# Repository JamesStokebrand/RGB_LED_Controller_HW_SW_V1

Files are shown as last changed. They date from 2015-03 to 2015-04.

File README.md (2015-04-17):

RGB LED Controller and Node Project Version 1:

This is the Software/Hardware for the Controller.

parts_list:
- Parts list pulled from EagleCAD project.
- Parts list spreadsheet listing quantity, parts numbers and supplier URLs.

src_code:
- CPP source code:
  * Makefile for AVR ATmega328p
  * XBee UART Driver and Communication wrapper
  * Support for AVR sleep and power reduction
  * Software based PWM (Timer based)
  * Timer class
  * RGB Controller State Machine
  * Button and rotary encoder input support

pcb_details:
- PCB Top/Bottom PNGs
- Eagle CAD schematic

PCBs are available for order on OSH Park:
https://oshpark.com/shared_projects/0rVsBJ7Y

project_case:
- project case files in STL format with associated photos

Further information on this project can be found here:
https://jamesstokebrand.wordpress.com/category/rgb-led-controller-and-node-v1/

14 Mar 2015 - Initial Commit 

23 Mar 2015 - Added Schematics and Project Cases

17 Apr 2015 - Updated source code to update mcu sleeping.

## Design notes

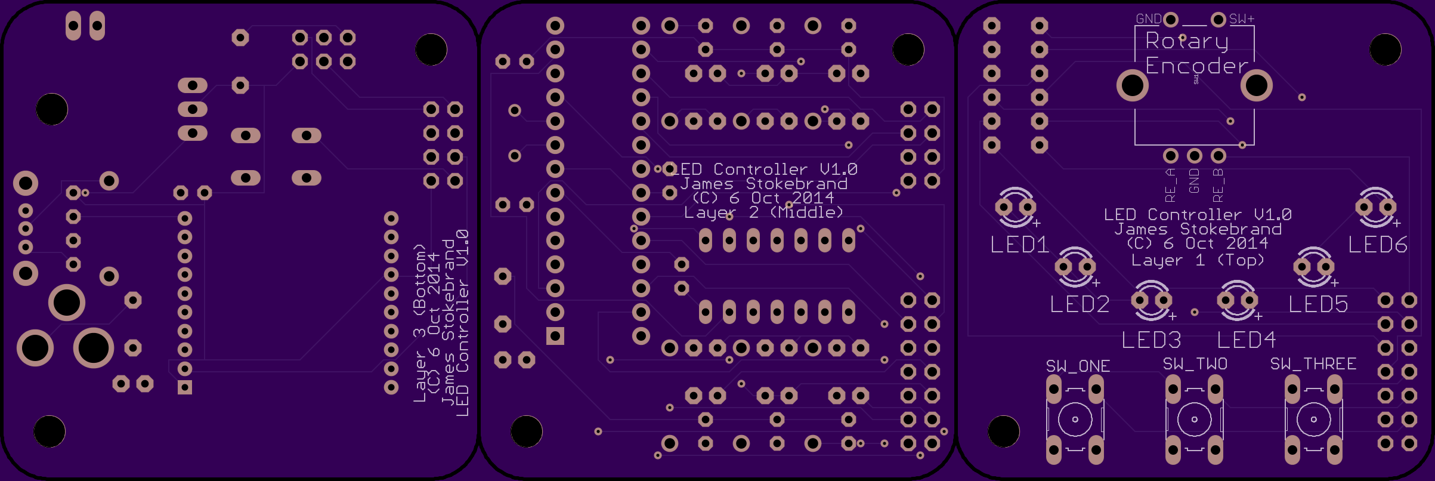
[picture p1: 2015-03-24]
pcb_details/Controller_PCB_Bottom_V1.png

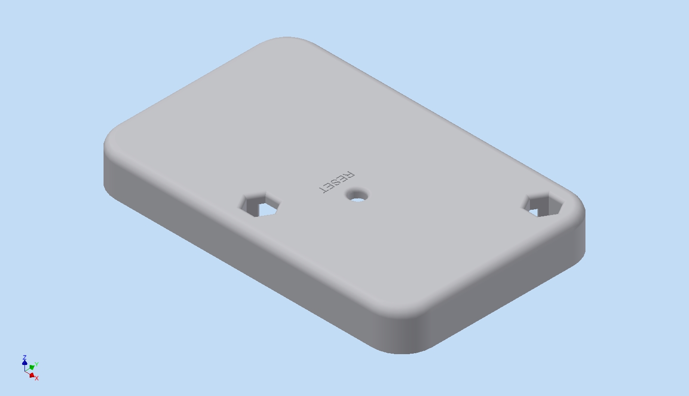
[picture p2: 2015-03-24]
project_case/Controller_Shell_Bottom_V1.jpg

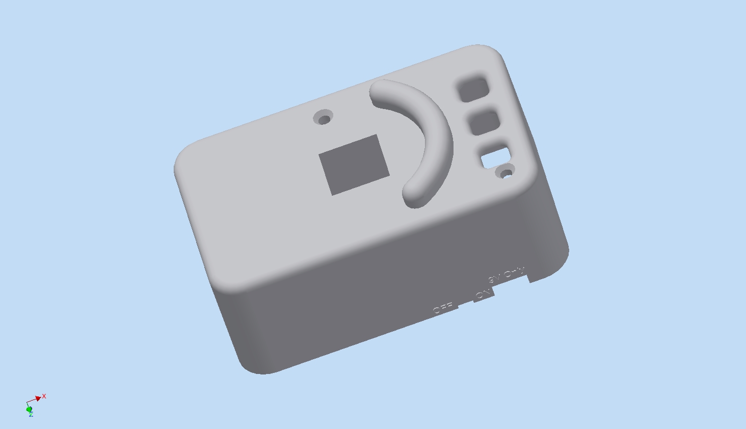
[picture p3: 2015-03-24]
project_case/Controller_Shell_Top_V1.jpg

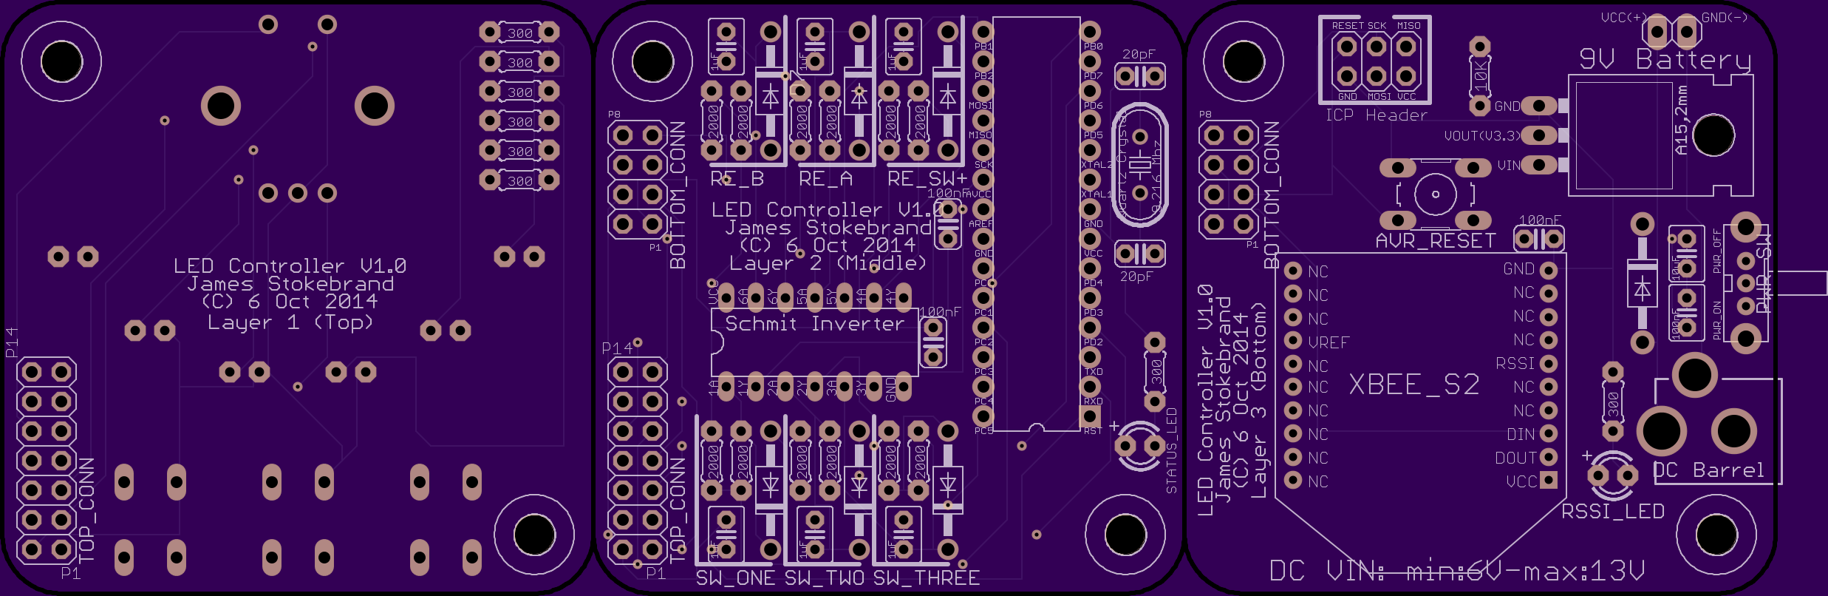
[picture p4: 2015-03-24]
pcb_details/Controller_PCB_Top_V1.png

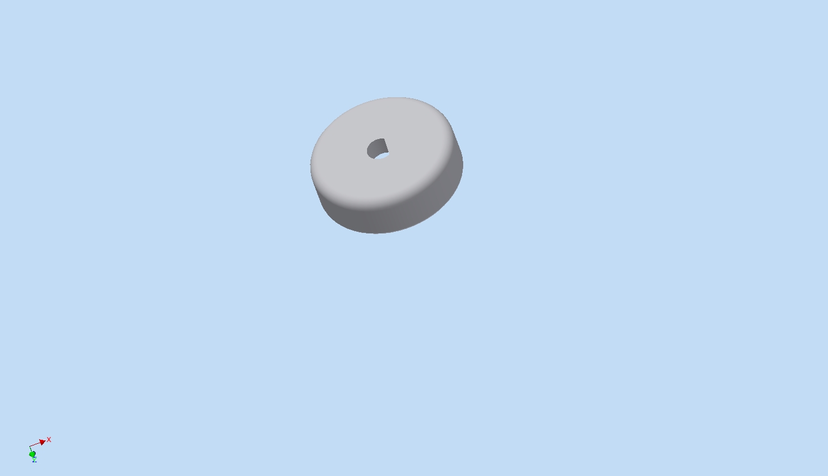
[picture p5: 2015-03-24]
project_case/Controller_Shell_Knob_v1.jpg

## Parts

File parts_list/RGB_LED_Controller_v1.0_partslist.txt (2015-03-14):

Partlist

Exported from ATmega328p_XBee_Devboard_v1.5.brd at 10/7/14 6:18 PM

EAGLE Version 6.6.0 Copyright (c) 1988-2014 CadSoft

Assembly variant: 

Part       Value                   Package          Library                       Position (inch)       Orientation

C1         100nF                   C025-030X050     adafruit                      (5.75 1)              R90
C2         10uF                    C025-030X050     adafruit                      (5.75 1.2)            R270
C3         100nF                   C025-024X044     adafruit                      (3.25 1.3)            R270
C4         20pF                    C025-024X044     adafruit                      (3.9 1.2)             R180
C5         1uF                     C025-030X050     adafruit                      (3.1 0.25)            R90
C6         1uF                     C025-030X050     adafruit                      (3.1 1.9)             R270
C7         1uF                     C025-030X050     adafruit                      (2.5 0.25)            R90
C8         1uF                     C025-030X050     adafruit                      (2.8 0.25)            R90
C9         20pf                    C025-024X044     adafruit                      (3.9 1.8)             R180
C10        1uF                     C025-030X050     adafruit                      (2.8 1.9)             R270
C11        1uF                     C025-030X050     adafruit                      (2.5 1.9)             R270
C12        100nF                   C025-024X044     adafruit                      (3.2 0.9)             R270
C13        100nF                   C025-024X044     adafruit                      (5.25 1.25)           R0
CN1        DC Barrel Jack          DCJACK_2MM_PTH   adafruit                      (6.2 0.6)             R90
D1         1N4004                  DO41-10          adafruit                      (5.6 1.1)             R270
D2         1N4004                  DO41-10          diode                         (2.65 0.4)            R90
D3         1N4004                  DO41-10          diode                         (3.25 0.4)            R90
D4         1N4004                  DO41-10          diode                         (3.25 1.75)           R270
D5         1N4004                  DO41-10          diode                         (2.95 0.4)            R90
D6         1N4004                  DO41-10          diode                         (2.95 1.75)           R270
D7         1N4004                  DO41-10          diode                         (2.65 1.75)           R270
IC1        LD117AV33               TO220L1          v-reg                         (5.4 1.6)             R270
ICP_HEADER                         2X03             pinhead                       (4.7 1.85)            R180
JP1                                2X04             pinhead                       (2.2 1.45)            R90
JP2                                2X04             pinhead                       (4.2 1.45)            R90
JP3                                2X07             pinhead                       (0.2 0.5)             R90
JP4                                2X07             pinhead                       (2.2 0.5)             R90
JP5                                1X02             pinhead                       (5.7 1.95)            R0
LED1       3mm RED                 LED3MM           adafruit                      (1.8 1.19)            MR180
LED2       3mm RED                 LED3MM           adafruit                      (1.55 0.94)           MR180
LED3       3mm RED                 LED3MM           adafruit                      (1.23 0.8)            MR180
LED4       3mm RED                 LED3MM           adafruit                      (0.87 0.8)            MR180
LED5       3mm RED                 LED3MM           adafruit                      (0.55 0.94)           MR180
LED6       3mm RED                 LED3MM           adafruit                      (0.29 1.19)           MR180
LED7       3mm RED                 LED3MM           adafruit                      (5.5 0.45)            R0
LED8       3mm RED                 LED3MM           adafruit                      (3.9 0.55)            R0
R1         300 Ohm                 0204/5           adafruit                      (1.8 1.95)            R0
R2         300 Ohm                 0204/5           adafruit                      (1.8 1.85)            R0
R3         300 Ohm                 0204/5           adafruit                      (1.8 1.75)            R0
R4         300 Ohm                 0204/5           adafruit                      (1.8 1.65)            R0
R5         2K                      0204/5           adafruit                      (3.05 0.5)            R270
R6         2K                      0204/5           adafruit                      (3.15 0.5)            R270
R7         2K                      0204/5           adafruit                      (3.05 1.65)           R90
R8         2K                      0204/5           adafruit                      (3.15 1.65)           R90
R9         10K Ohm                 0204/5           adafruit                      (5.05 1.8)            R90
R10        2K                      0204/5           adafruit                      (2.45 0.5)            R270
R11        2K                      0204/5           adafruit                      (2.55 0.5)            R270
R12        2K                      0204/5           adafruit                      (2.75 0.5)            R90
R13        2K                      0204/5           adafruit                      (2.85 0.5)            R270
R14        300 Ohm                 0204/5           adafruit                      (3.95 0.8)            R270
R15        2K                      0204/5           adafruit                      (2.75 1.65)           R90
R16        2K                      0204/5           adafruit                      (2.85 1.65)           R90
R17        2K                      0204/5           adafruit                      (2.55 1.65)           R90
R18        2K                      0204/5           adafruit                      (2.45 1.65)           R90
R19        300 Ohm                 0204/5           adafruit                      (1.8 1.55)            R180
R20        300 Ohm                 0204/5           adafruit                      (1.8 1.45)            R180
R21        300 Ohm                 0204/5           adafruit                      (5.5 0.7)             R270
S1         Swittch                 B3F-10XX         switch-omron                  (1.05 0.3)            MR270
S2         RESET                   B3F-10XX         switch-omron                  (4.9 1.4)             R0
S3         Swittch                 B3F-10XX         switch-omron                  (0.55 0.3)            MR270
S5         Swittch                 B3F-10XX         switch-omron                  (1.55 0.3)            MR270
S6         EG1213                  EG1213           adafruit                      (5.95 1.1)            R90
SW1        ROTARTY_ENCODER         ROTARY_ENC_PLAIN SparkFun-Electromechanical    (1.05 1.7)            MR270
U1         ATMEGA328P-PU-1030050P1 DIP28            OPL_Eagle_Library_Seeed_Sudio (3.55 1.3)            R180
V1         7414N                   DIL14            74ttl-din                     (2.8 0.9)             R0
XBEE       XBEE                    XBEE             adafruit                      (4.85 0.65)           R180
Y1          9.216 Mhz              HC49U-V          SparkFun-FreqCtrl             (3.9 1.5)             R90

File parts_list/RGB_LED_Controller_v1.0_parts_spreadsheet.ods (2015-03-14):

10/03/14 | Atmega328P Xbee Development Board v1.5
Count | Part Name/Description | Pins/Pkg | Pin Spacing | Manuf Part # | Supplier | Supplier Part # | Price Ea (~) | Total | URL
1 | 74HC14 IC INV HEX SCHMITT TRIG 14-DIP | DIP14 | 0.1”(2.54mm) | TC74HC14AP(F) | Digikey | TC74HC14APF-ND | 0.51 | 0.51 | http://www.digikey.com/product-detail/en/TC74HC14AP%28F%29/TC74HC14APF-ND/870479
1 | CONN IC SOCKET VERT 14POS TIN | DIP14 | 0.1”(2.54mm) | ED14DT | Digikey | ED3045-5-ND | 0.17 | 0.17 | http://www.digikey.com/product-detail/en/ED14DT/ED3045-5-ND/4147595
1 | 3.3v Voltage Regulator | 3 | 0.1”(2.54mm) | LD1117V33 | Digikey | 497-1491-5-ND | 0.64 | 0.64 | http://www.digikey.com/product-detail/en/LD1117V33/497-1491-5-ND/586012
4 | CAP CER 0.1UF 25V RADIAL (100nF) | 2 | 0.1”(2.54mm) | FK18X7R1E104K | Digikey | 445-8421-ND | 0.29 | 1.16 | http://www.digikey.com/product-detail/en/FK18X7R1E104K/445-8421-ND/2815351
2 | CAP CER 20PF 50V 5% RADIAL | 2 | 0.1”(2.54mm) | C317C200J5G5TA | Digikey | 399-8916-ND | 0.51 | 1.02 | http://www.digikey.com/product-detail/en/C317C200J5G5TA/399-8916-ND/3522973
1 | CAP CER 10UF 25V 10% RADIAL | 2 | 0.1”(2.54mm) | FK16X7R1E106K | Digikey | 445-8351-ND | 0.65 | 0.65 | http://www.digikey.com/product-detail/en/FK16X7R1E106K/445-8351-ND/2815281
6 | CAP CER 1UF 25V 10% RADIAL | 2 | 0.1”(2.54mm) | FK18X5R1E105K | Digikey | 445-8410-ND | 0.34 | 2.04 | http://www.digikey.com/product-detail/en/FK18X5R1E105K/445-8410-ND/2815340
1 | CRYSTAL 9.216MHZ 20PF THRU | 2 | 4.8mm | ECS-92.1-20-4X | Digikey | X1096-ND | 0.81 | 0.81 | http://www.digikey.com/product-detail/en/ECS-92.1-20-4X/X1096-ND/827587
7 | LED SS RED DIFFUSED PCB 3MM | 2 | 0.1”(2.54mm) | MV50640 | Digikey | 1080-1100-ND | 0.42 | 2.94 | http://www.digikey.com/product-detail/en/MV50640/1080-1100-ND/2675591
1 | LED SS YELLOW DIFFUSED PCB 3MM | 2 | 0.1”(2.54mm) | MV5374C | Digikey | 1080-1106-ND | 0.46 | 0.46 | http://www.digikey.com/product-detail/en/MV5374C/1080-1106-ND/2675597
8 | RES 300 OHM 1/4W 1% AXIAL | 2 | 0.1”(2.54mm) | RNMF14FTC300R | Digikey | S300CACT-ND | 0.14 | 1.12 | http://www.digikey.com/product-detail/en/RNMF14FTC300R/S300CACT-ND/2617485
4 | SWITCH TACTILE SPST-NO 0.05A 24V | 4 | 6.5mmX4.5mm | B3F-1020 | Digikey | SW402-ND | 0.41 | 1.64 | http://www.digikey.com/product-detail/en/B3F-1020/SW402-ND/44059
1 | SWITCH SLIDE SPDT 30V RT ANGLE | 4 | Various | EG1213 | Digikey | EG1906-ND | 0.58 | 0.58 | http://www.digikey.com/product-detail/en/EG1213/EG1906-ND/101735
1 | Rotary Encoder | 7 | N/A | COM-09117 | Sparkfun | COM-09117 | 2.95 | 2.95 | https://www.sparkfun.com/products/9117
1 | ATMEGA328P-PU (IC MCU 8BIT 32KB FLASH 28DIP) | DIP28 | 0.1”(2.54mm) | ATMEGA328P-PU | Digikey | ATMEGA328P-PU-ND | 3.74 | 3.74 | http://www.digikey.com/product-detail/en/ATMEGA328P-PU/ATMEGA328P-PU-ND/1914589
1 | CONN IC SOCKET VERT 28POS TIN | DIP28 | 0.1”(2.54mm) | ED281DT | Digikey | ED3050-5-ND | 0.31 | 0.31 | http://www.digikey.com/product-detail/en/ED281DT/ED3050-5-ND/4147600
1 | DC Barrel Power Jack/connector | 3 | 4.7mm | PJ-002A | Digikey | CP-002A-ND | 0.93 | 0.93 | http://www.digikey.com/product-detail/en/PJ-002A/CP-002A-ND/96962
7 | DIODE GEN PURPOSE 50V 1A DO41 | 2 | N/A | 1N4001-TP | Digikey | 1N4001-TPMSCT-ND | 0.11 | 0.77 | http://www.digikey.com/product-detail/en/1N4001-TP/1N4001-TPMSCT-ND/773688
12 | RES 2K OHM 1/4W 1% AXIAL | 2 | 0.1”(2.54mm) | RNMF14FTC2K00 | Digikey | S2KCACT-ND | 0.14 | 1.68 | http://www.digikey.com/product-detail/en/RNMF14FTC2K00/S2KCACT-ND/2617814
1 | RES 10K OHM 1/4W 1% AXIAL | 2 | 0.1”(2.54mm) | RNMF14FTC10K0 | Digikey | S10KCACT-ND | 0.14 | 0.14 | http://www.digikey.com/product-detail/en/RNMF14FTC10K0/S10KCACT-ND/2617809
1 | MODULE ZIGBEE W/WIRED ANT | 20 | 0.079”(2mm) | XB24-Z7WIT-004 | Digikey | 602-1098-ND | 17 | 17 | http://www.digikey.com/product-detail/en/XB24-Z7WIT-004/602-1098-ND/1942304
2 | CONN RECEPT 2MM SINGLE STR 10POS (1x10 2mm strip XBEE Socket) | 10 | 0.079”(2mm) | NPPN101BFCN-RC | Digikey | S5751-10-ND | 1.23 | 2.46 | http://www.digikey.com/product-detail/en/NPPN101BFCN-RC/S5751-10-ND/804812
1 | CONN HEADER 6POS 2.54 (2x3) | 2x3 | 0.1”(2.54mm) | 61200621621 | Digikey | 732-5394-ND | 0.82 | 0.82 | http://www.digikey.com/product-detail/en/61200621621/732-5394-ND/4846913
1 | CONN HEADER FMALE 8PS .1" DL TIN (2x4) | 2x4 | 0.1”(2.54mm) | PPTC042LFBN-RC | Digikey | S7072-ND | 0.83 | 0.83 | http://www.digikey.com/product-detail/en/PPTC042LFBN-RC/S7072-ND/810211
1 | CONN HEADER FMAL 14PS .1" DL TIN (2x7) | 2x14 | 0.1”(2.54mm) | PPTC072LFBN-RC | Digikey | S7075-ND | 1.16 | 1.16 | http://www.digikey.com/product-detail/en/PPTC072LFBN-RC/S7075-ND/810213
1 | Header, straight, 0.1”(2.54mm) pitch, male 5.84mm high (2x36 pin headers) | 2x36 | 0.1”(2.54mm) | 67996-472HLF | Digikey | 609-3494-ND | 1.45 | 1.45 | http://www.digikey.com/product-detail/en/67996-472HLF/609-3494-ND/1486045
1 | 9V SNAP I STYLE 3" WIRE LEADS | 2 | 0.1”(2.54mm) | BS3I | Digikey | BS3I-ND | 0.59 | 0.59 | http://www.digikey.com/product-detail/en/BS3I/BS3I-ND/2439485
 | On Hand |  |  |  |  |  |  | 48.57
 | Ordered from Digikey

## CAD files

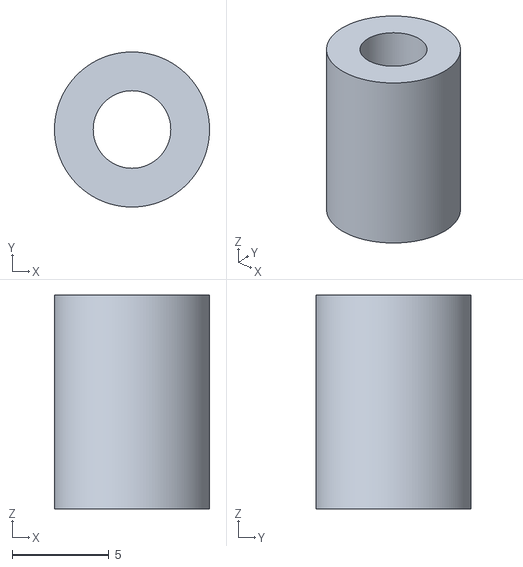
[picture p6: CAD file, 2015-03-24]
project_case/PCB_Spacer.stl
8.00 x 8.00 x 11.0

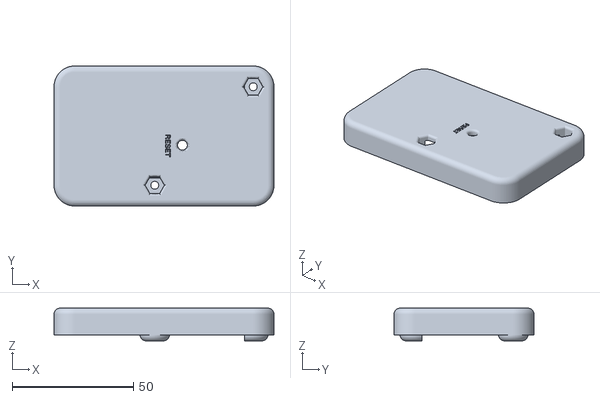
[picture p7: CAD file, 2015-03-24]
project_case/Controller_Shell_Top_V1.stl
90.8 x 57.8 x 13.5

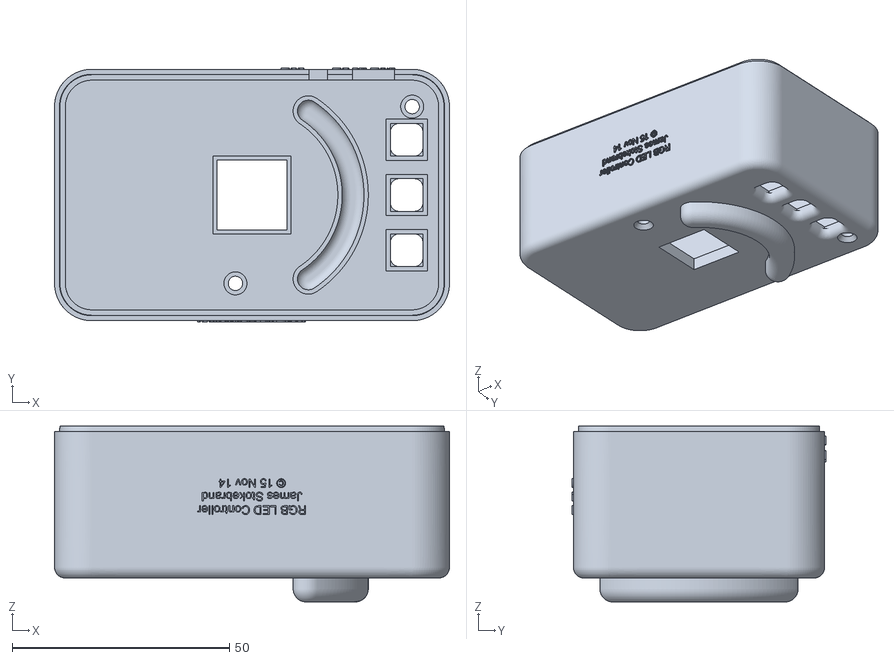
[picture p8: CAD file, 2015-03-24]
project_case/Controller_Shell_Bottom_V1.stl
90.8 x 58.5 x 40.5

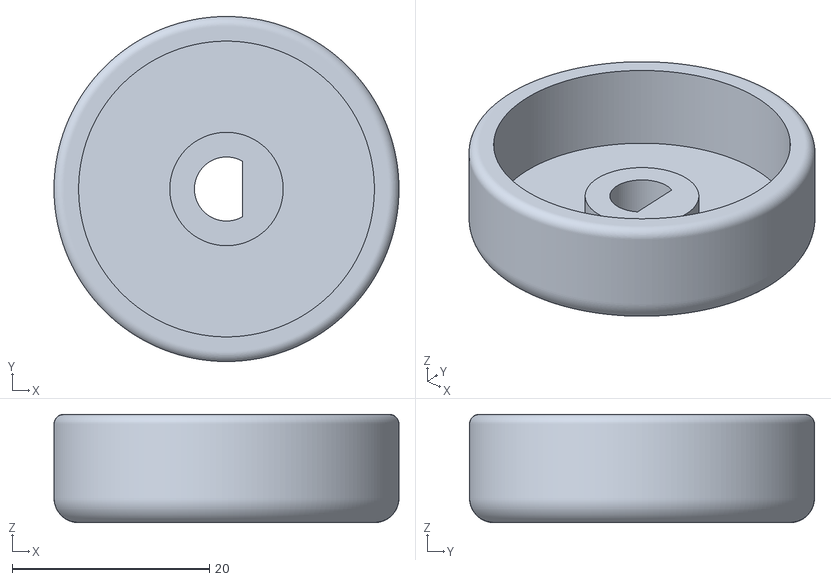
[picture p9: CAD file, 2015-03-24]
project_case/Controller_Shell_Knob_v1.stl
35.0 x 35.0 x 11.0

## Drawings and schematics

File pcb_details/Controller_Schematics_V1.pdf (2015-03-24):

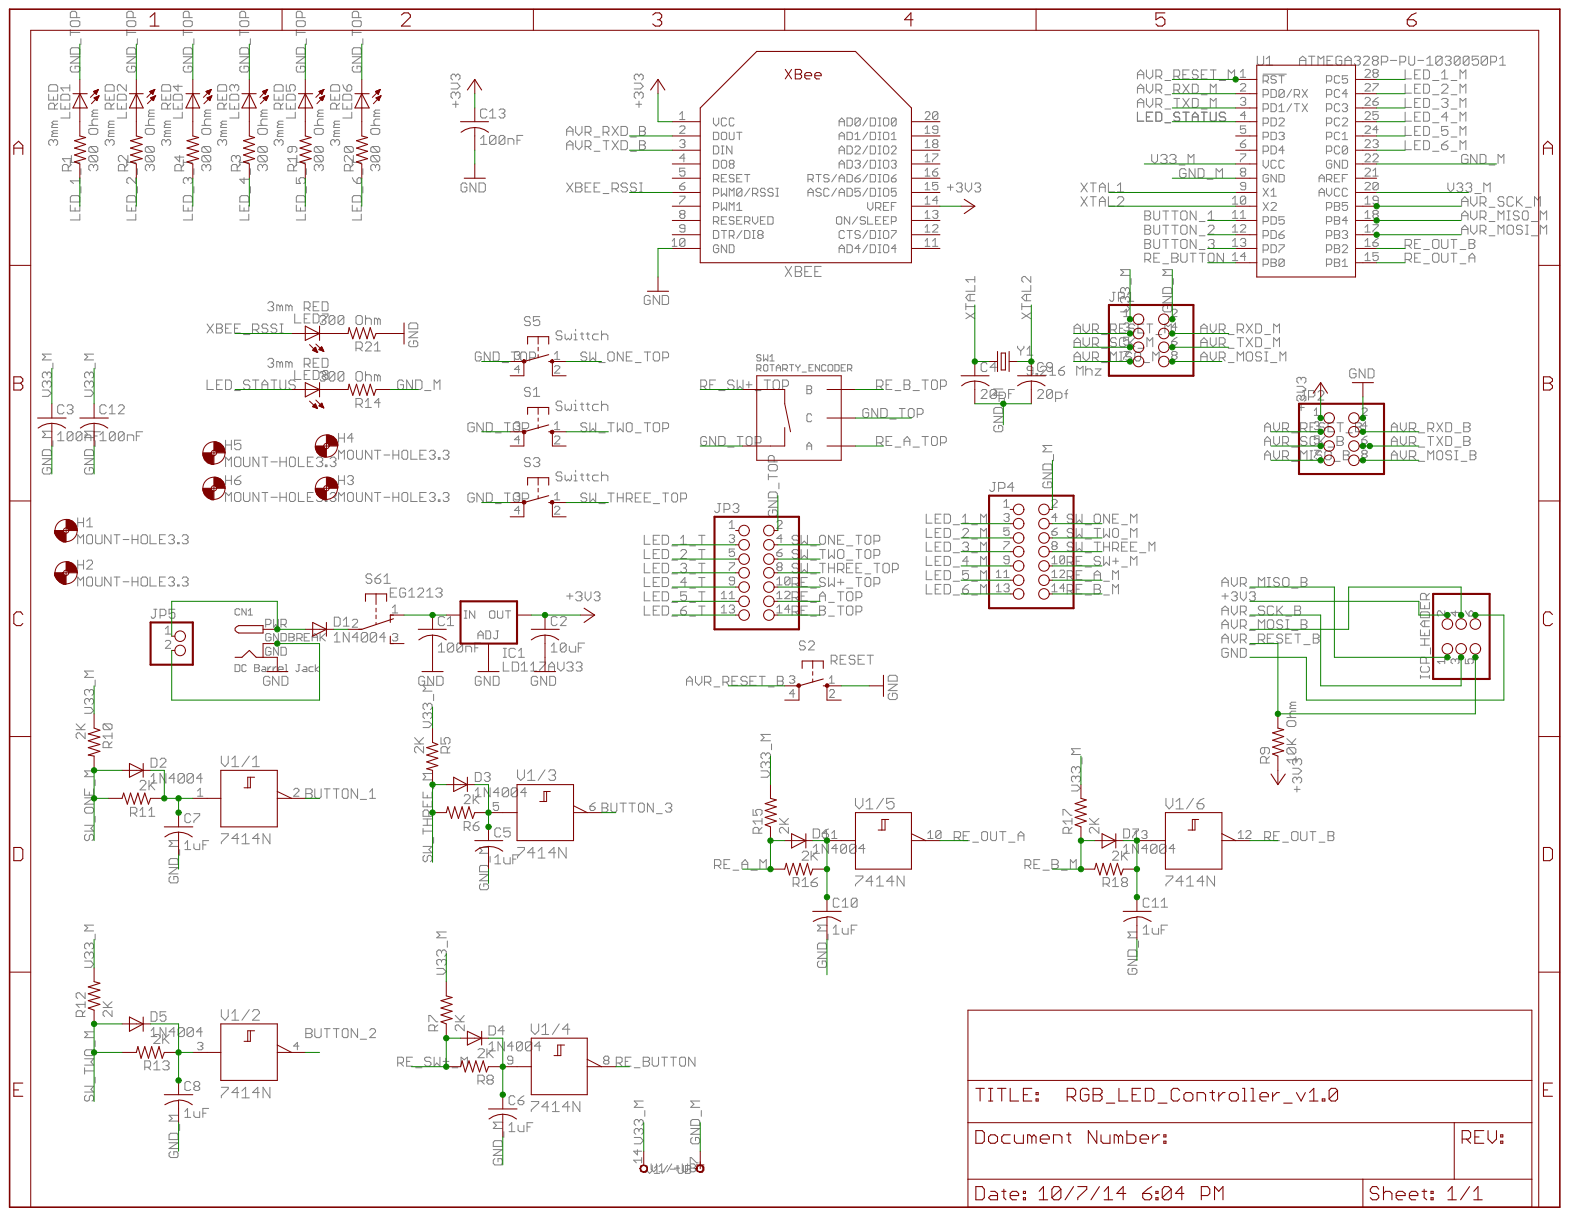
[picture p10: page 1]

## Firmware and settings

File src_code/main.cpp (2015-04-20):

/****************************************************
    RGB LED Controller v1 hardware

    File:   main.cpp
    Author: James Stokebrand
    jamesstokebrand AT gmail DOT com

    main.cpp file is part of the RGB LED Controller and Node 
     version 1 hardware project.

    This file contains the main() method and the forever loop.  It 
     creates the RGB Controller State machine and the code to sleep the AVR
     chip.
     
    Copyright (C) 2015 - James Stokebrand - 2015 Mar 12

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
    Rev History:
     When         Who                Description of change
    -----------  ----------         ------------------------
    2014 Nov 18  James Stokebrand   Initial creation.

*****************************************************/

/*****************************************************

AVR Chip Fuses:

--- FUSES ---
BODLEVEL    = DISABLED
RSTDISBL    = [ ]
DWEN        = [ ]
SPIEN       = [X]
WDTON       = [ ]
EESAVE      = [ ]
BOOTSZ      = 2048W_3800
BOOTRST     = [ ]
CKDIV8      = [ ]
CKOUT       = [ ]
SUT_CKSEL   = INTRCOSC_8MHZ_6CK_14CK_0MS

EXTENDED    = 0xFF (valid)
HIGH        = 0xD9 (valid)
LOW         = 0xC2 (valid)

--- LOCK BITS ---
LB      = NO_LOCK
BLB0    = NO_LOCK
BLB1    = NO_LOCK

LOCKBIT = 0xFF (valid)

*****************************************************/

#include <avr/io.h>
//#include <util/delay.h>
#include <avr/interrupt.h>

#ifndef NEW_H
#include "new.h"
#endif

#ifndef _BUTTON_CLASS_H_
#include "button_class.h"
#endif

#ifndef _EVENT_QUEUE_H_
#include "event_queue.h"
#endif

#ifndef _ROTARY_ENCODER_CLASS_H_
#include "rotary_encoder_class.h"
#endif

#ifndef _COMM_CLASS_H_
#include "comm_class.h"
#endif

#ifndef _RGB_CONTROLLER_STATE_MACHINE_H_
#include "rgb_controller_state_machine.h"
#endif

#ifndef _PWM_SIX_DISPLAY_H_
#include "pwm_six_display.h"
#endif

#ifndef _MCU_SLEEP_CLASS_H_
#include "mcu_sleep_class.h"
#endif

int main(void)
{
    // Enable MCU sleep
    mcu_sleep_class::getInstance()->EnableSleep();

    // Idle is the default power mode ... but set it anyway.
    mcu_sleep_class::getInstance()->SetSleepMode(mcu_sleep_class::E_MCU_SLEEP_MODE_IDLE);

    // Try to save more power.  Set these pins as input and enable pullup resistor
    mcu_sleep_class::getInstance()->SetInputAndPullupResistor(IOPinDefines::E_PinDef::E_PIN_PD3);
    mcu_sleep_class::getInstance()->SetInputAndPullupResistor(IOPinDefines::E_PinDef::E_PIN_PD4);
    mcu_sleep_class::getInstance()->SetInputAndPullupResistor(IOPinDefines::E_PinDef::E_PIN_PB6);
    mcu_sleep_class::getInstance()->SetInputAndPullupResistor(IOPinDefines::E_PinDef::E_PIN_PB7);

    // MCU Programming header.  Only used when programming.  Turn these off also.
    mcu_sleep_class::getInstance()->SetInputAndPullupResistor(IOPinDefines::E_PinDef::E_PIN_PB5);
    mcu_sleep_class::getInstance()->SetInputAndPullupResistor(IOPinDefines::E_PinDef::E_PIN_PB4);
    mcu_sleep_class::getInstance()->SetInputAndPullupResistor(IOPinDefines::E_PinDef::E_PIN_PB3);

    // Event queue that really ties the room together
    EventQueue event_queue;

    // BLUE
    // Buttons (count three)
    ButtonClass Button_1(E_BUTTON_01
                        ,IOPinDefines::E_PinDef::E_PIN_PD7
                        ,IOPinDefines::E_PinIntrType::E_PIN_INTR_ANY_EDGE);
    Button_1.Attach(&event_queue);

    // GREEN
    ButtonClass Button_2(E_BUTTON_02
                        ,IOPinDefines::E_PinDef::E_PIN_PD6
                        ,IOPinDefines::E_PinIntrType::E_PIN_INTR_ANY_EDGE);
    Button_2.Attach(&event_queue);

    // RED
    ButtonClass Button_3(E_BUTTON_03
                        ,IOPinDefines::E_PinDef::E_PIN_PD5
                        ,IOPinDefines::E_PinIntrType::E_PIN_INTR_ANY_EDGE);
    Button_3.Attach(&event_queue);


    // Rotary Encoder (CCW/CW and button press/release)
    RotaryEncoderClass RotaryEncoder(E_ROTARY_ENCODER_01
                        ,IOPinDefines::E_PinDef::E_PIN_PB1
                        ,IOPinDefines::E_PinDef::E_PIN_PB2
                        ,IOPinDefines::E_PinIntrType::E_PIN_INTR_ANY_EDGE);
    RotaryEncoder.Attach(&event_queue);

    ButtonClass RotaryEncoderButton(E_ROTARY_ENCODER_01
                        ,IOPinDefines::E_PinDef::E_PIN_PB0
                        ,IOPinDefines::E_PinIntrType::E_PIN_INTR_ANY_EDGE);
    RotaryEncoderButton.Attach(&event_queue);

    // RGB Controller state machine
    rgb_controller_state_machine RGB_Controller(&event_queue);

    sei();

    event_element_class anEvent;

    for (;;) 
    {
        if (event_queue.Dequeue(anEvent))
        {

            // Process events through the 
            //  RGB Controller state machine
            RGB_Controller.process(anEvent);

        } else {

            // Nothing in the queue ... go to sleep
            mcu_sleep_class::getInstance()->GoMakeSleepNow();

        }
    }

    return 0;
}

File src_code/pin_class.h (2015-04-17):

#ifndef _PIN_CLASS_H_
#define _PIN_CLASS_H_

/****************************************************
    Pin Class

    File:   pin_class.h
    Author: James Stokebrand
    jamesstokebrand AT gmail DOT com

    pin_class.h file is part of the RGB LED Controller and Node 
     version 1 hardware project.

    This file implements the input/output pin definitions.  This 
     simplifies the defining of pins by an enum and allows the 
     abstraction of pin resources.  (IE Buttons/LEDs/Rotary Encoders etc)

    Copyright (C) 2015 - James Stokebrand - 2015 Mar 12

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
    Rev History:
     When         Who                Description of change
    -----------  ----------         ------------------------
    2014 Aug 14  James Stokebrand   Initial creation.

*****************************************************/


#include <avr/io.h>

#ifndef _OBSERVER_CLASS_H_
#include "observer_class.h"
#endif


#define PIN_CHANGE_INTERRUPT_CONTROL_REGISTER   PCICR

// PCIE0 controls interrupts for the PB[0:7] pins
#define PIN_CHANGE_INTERRUPT_ENABLE_ZERO        PCIE0
// PCIE1 controls interrupts for the PC[0:6] pins
#define PIN_CHANGE_INTERRUPT_ENABLE_ONE         PCIE1
// PCIE2 controls interrupts for the PD[0:7] pins
#define PIN_CHANGE_INTERRUPT_ENABLE_TWO         PCIE2

// Writing a 1 to the ISC10 bit in the EICRA enables interrupts on Rising/Falling edges
#define EXTERNAL_INTERRUPT_CONTROL_REGISTER_A   EICRA
#define INTERRUPT_SENSE_CONTROL_ONE_BIT_ZERO    ISC10

class IOPinDefines
{
public:

    // These are specific to the ATmega328p
    typedef enum {
         E_PIN_PORTB_BASE = 0
        ,E_PIN_PB0 = PB0 + E_PIN_PORTB_BASE
        ,E_PIN_PB1 = PB1 + E_PIN_PORTB_BASE
        ,E_PIN_PB2 = PB2 + E_PIN_PORTB_BASE
        ,E_PIN_PB3 = PB3 + E_PIN_PORTB_BASE
        ,E_PIN_PB4 = PB4 + E_PIN_PORTB_BASE
        ,E_PIN_PB5 = PB5 + E_PIN_PORTB_BASE
        ,E_PIN_PB6 = PB6 + E_PIN_PORTB_BASE
        ,E_PIN_PB7 = PB7 + E_PIN_PORTB_BASE

        ,E_PIN_PORTC_BASE = E_PIN_PB7 + 1
        ,E_PIN_PC0 = PC0 + E_PIN_PORTC_BASE
        ,E_PIN_PC1 = PC1 + E_PIN_PORTC_BASE
        ,E_PIN_PC2 = PC2 + E_PIN_PORTC_BASE
        ,E_PIN_PC3 = PC3 + E_PIN_PORTC_BASE
        ,E_PIN_PC4 = PC4 + E_PIN_PORTC_BASE
        ,E_PIN_PC5 = PC5 + E_PIN_PORTC_BASE
        ,E_PIN_PC6 = PC6 + E_PIN_PORTC_BASE
        // NOTE there is no PC7

        ,E_PIN_PORTD_BASE = E_PIN_PC6 + 1
        ,E_PIN_PD0 = PD0 + E_PIN_PORTD_BASE
        ,E_PIN_PD1 = PD1 + E_PIN_PORTD_BASE
        ,E_PIN_PD2 = PD2 + E_PIN_PORTD_BASE
        ,E_PIN_PD3 = PD3 + E_PIN_PORTD_BASE
        ,E_PIN_PD4 = PD4 + E_PIN_PORTD_BASE
        ,E_PIN_PD5 = PD5 + E_PIN_PORTD_BASE
        ,E_PIN_PD6 = PD6 + E_PIN_PORTD_BASE
        ,E_PIN_PD7 = PD7 + E_PIN_PORTD_BASE
        ,E_PIN_LAST_DEFINE 
    } E_PinDef;

    // Currently only support Disabled or Rise/Falling edge triggered interrupts
    typedef enum {
         E_PIN_INTR_DISABLED
        ,E_PIN_INTR_ANY_EDGE
        ,E_PIN_INTR_LAST_DEFINE
    } E_PinIntrType;

    IOPinDefines(E_PinDef const &aPin, E_PinIntrType const &anIntr = E_PIN_INTR_DISABLED);
    virtual ~IOPinDefines() {}

    volatile uint8_t* _PinReg;
    volatile uint8_t* _PortReg;
    volatile uint8_t* _DDRReg;
    E_PinIntrType _PinInterruptType;
    E_PinDef _Pin;
    uint8_t _Bit;
};

class InputPinClass 
: public IOPinDefines
{
public:
    InputPinClass(IOPinDefines::E_PinDef const &A
                 ,IOPinDefines::E_PinIntrType const &B = IOPinDefines::E_PinIntrType::E_PIN_INTR_DISABLED)
    : IOPinDefines(A,B)
    {
        // Set pin as input
        *(_DDRReg) &= ~(1<<_Bit);

        // Activate pull up resistor
        *(_PortReg) |= (1<<_Bit);
    }
     
    virtual ~InputPinClass() {}

    inline bool Read() __attribute__((always_inline))
    {
        return ((*(_PinReg) & (1<<_Bit)) ? true : false);
    }

};

class OutputPinClass
: public IOPinDefines
{
public:
    OutputPinClass(IOPinDefines::E_PinDef const &A)
    : IOPinDefines(A,IOPinDefines::E_PinIntrType::E_PIN_INTR_DISABLED) 
    { }

    virtual ~OutputPinClass() {}

    virtual void On() = 0;
    virtual void Off() = 0;

    inline void Toggle() __attribute__((always_inline))
    {
        *(_PortReg) ^= (1<<_Bit);
    }
};

class LED_CommonCathode // LED tied to ground 
: public OutputPinClass
{
public:
    LED_CommonCathode(IOPinDefines::E_PinDef const &A)
    : OutputPinClass(A)
    {
        // Init the pin to off 
        Off();

        // Set the pin as an output
        *(_DDRReg) |= (1<<_Bit);
    }

    virtual ~LED_CommonCathode() {}

    virtual inline void On() __attribute__((always_inline))
    {
        *(_PortReg) |= (1<<_Bit);
    }

    virtual inline void Off() __attribute__((always_inline))
    {
        *(_PortReg) &= ~(1<<_Bit);
    }
};
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

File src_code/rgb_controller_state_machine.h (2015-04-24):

#ifndef _RGB_CONTROLLER_STATE_MACHINE_H_
#define _RGB_CONTROLLER_STATE_MACHINE_H_

/****************************************************
    RGB LED Controller State Machine

    File:   rgb_controller_state_machine.h
    Author: James Stokebrand
    jamesstokebrand AT gmail DOT com

    rgb_controller_state_machine.h file is part of the RGB LED Controller and Node 
     version 1 hardware project.

    This file implements the RGB LED Controller State Machine.  This 
     machine will send commands to the RGB LED Node to change the 
     colors of the common anode RGB LED.

    Copyright (C) 2015 - James Stokebrand - 2015 Mar 12

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
    Rev History:
     When         Who                Description of change
    -----------  ----------         ------------------------
    2014 Oct 05  James Stokebrand   Initial creation.

*****************************************************/

#ifndef _STATE_CLASS_H_
#include "state_class.h"
#endif

#ifndef _COMM_CLASS_H_
#include "comm_class.h"
#endif

#ifndef _TIMER_CLASS_H_
#include "timer_class.h"
#endif

#ifndef _PWM_SIX_DISPLAY_H_
#include "pwm_six_display.h"
#endif

#define DEBUG 0

#define ABS(a) ((a)<0?-(a):a)

class rgb_controller_state_machine
:public base_state_class
{
public:

    typedef enum {
         E_COLOR_RGB    = 2  // Red/Green/Blue Color Model
        ,E_COLOR_HSL    = 7  // Hue/Saturation/Luminosity Color Model
        ,E_COLOR_SCRIPT = 13 // Play script state

        // Must be the last ENUM 
        ,E_COLOR_MODEL_LAST
    } E_ColorModel;


    typedef enum {
         E_STATUS_LED_ENABLED  = 4  // Status LED is ON  - displaying when the MCU is awake.
        ,E_STATUS_LED_DISABLED = 11 // Status LED is OFF - displaying ... nothing.

        // Must be the last ENUM
        ,E_STATUS_LED_LAST_ENUM
    } E_StatusLED;

    rgb_controller_state_machine(EventQueue *event_queue)
    : base_state_class((STATE)&rgb_controller_state_machine::STATE_IDLE)
    , _colorModel(E_COLOR_HSL) // Init to the HSL color model.
    , _statusLED(E_STATUS_LED_DISABLED) // Init Status LED to disabled.
    , _CURRENT_ADDRESS(MIN_ADDRESS)
    , _event_queue(event_queue)
    , _timerID(255)
    , _rotary_encoder_count(0)
    , PwmDisplay(
         IOPinDefines::E_PinDef::E_PIN_PC5
        ,IOPinDefines::E_PinDef::E_PIN_PC4
        ,IOPinDefines::E_PinDef::E_PIN_PC2
        ,IOPinDefines::E_PinDef::E_PIN_PC3
        ,IOPinDefines::E_PinDef::E_PIN_PC1
        ,IOPinDefines::E_PinDef::E_PIN_PC0
        // The true here makes these LEDs common cathode
        ,true)
    {
        // Attach the USART to the event queue
        _Comm.Attach(event_queue);
        _timer.Attach(event_queue);

        // Disable Status LED.
        mcu_sleep_class::getInstance()->DisableStatusLED();
    }

    virtual ~rgb_controller_state_machine() {}

private:

    void STATE_IDLE(event_element_class &A)
    {

#if DEBUG
_Comm.encode(A);
#endif

        switch(A.get_current_hardware())
        {
        case E_STATE_MACHINE:
            if (A.get_current_event() == E_ENTER_STATE)
            {
                // Set the Idle timer
                _timerID = _timer.set(IDLE_TIMEOUT);
                _timer.start(_timerID);
            }
            if (A.get_current_event() == E_EXIT_STATE)
            {
                // Cancel Idle timer
                _timer.stop(_timerID);
                _timerID = 0;
            }
        break;
        case E_TIMER_01:
            if ((A.get_current_event() == E_TIMER_EXPIRE) &&
                (A.get_current_data() == _timerID))
            {
                // Idle Timeout.  Turn off display
                PwmDisplay.Off();
            }
        break;
        case E_BUTTON_01:
            if (A.get_current_event() == E_BUTTON_IS_PRESSED)
            {
                // If _colorModel is E_COLOR_SCRIPT .. pushing button1 means 
                //  adjust the script value.
                if (_colorModel == E_COLOR_SCRIPT) {
                    send_msg(E_SET_SCRIPT);
                }

                // Button 1 has been pressed ... transition
                TRAN((STATE)&rgb_controller_state_machine::STATE_BUTTON_1_PRESSED);
            }
        break;
        case E_BUTTON_02:
            if (A.get_current_event() == E_BUTTON_IS_PRESSED)
            {
                // If _colorModel is E_COLOR_SCRIPT .. pushing button2 means 
                //  adjust the delay value.
                if (_colorModel == E_COLOR_SCRIPT) {
                    send_msg(E_SET_DELAY);
                }

                // Button 2 has been pressed ... transition
                TRAN((STATE)&rgb_controller_state_machine::STATE_BUTTON_2_PRESSED);
            }
        break;
        case E_BUTTON_03:
            if (A.get_current_event() == E_BUTTON_IS_PRESSED)
            {
                // If _colorModel is E_COLOR_SCRIPT .. pushing button3 means 
                //  adjust the fade speed value.
                if (_colorModel == E_COLOR_SCRIPT) {
                    send_msg(E_SET_FADE);
                }

                // Button 3 has been pressed ... transition
                TRAN((STATE)&rgb_controller_state_machine::STATE_BUTTON_3_PRESSED);
            }
        break;
        case E_ROTARY_ENCODER_01:
            switch(A.get_current_event())
            {
            case E_ROTARY_ENCODER_ROTATED_CW:
                send_msg(E_RE_CW);
            break;
            case E_ROTARY_ENCODER_ROTATED_CCW:
                send_msg(E_RE_CCW);
            break;
            case E_BUTTON_IS_PRESSED:
                send_msg(E_RE_PRESSED);
            break;
            case E_BUTTON_IS_RELEASED:
                send_msg(E_RE_RELEASED);
            break;
            default:
                // Ignore all other events
            break;
            }
        break;
        case E_RGB_NODE: // Feedback from the Node

            // Reset the idle timer to make sure to 
            //  turn off the display.

            // Cancel Idle timer
            _timer.stop(_timerID);
            _timerID = 0;

            // Set the Idle timer
            _timerID = _timer.set(IDLE_TIMEOUT);
            _timer.start(_timerID);
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

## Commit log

2015-03-14 RGB LED Controller and Node Project Version 1:
    This is the Software/Hardware for the Controller.
    parts_list:
    - Parts list pulled from EagleCAD project.
    - Parts list spreadsheet listing quantity, parts numbers and supplier URLs.
    src_code:
    - CPP source code:
    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
    [RGB_LED_Controller_v1.0_parts_spreadsheet.ods]
2015-03-24 Added pcb_details directory with Schematic and Top/Bottom representations.
    Added project_case directory with:
    Controller_Shell_Bottom_V1.stl - Bottom clamshell
    Controller_Shell_Top_V1.stl - Top clamshell
    Controller_Shell_Knob_V1.stl - rotary encoder knob
    [Controller_Shell_Bottom_V1.stl, Controller_Shell_Knob_v1.stl, Controller_Shell_Top_V1.stl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]
2015-04-17 Moved InterruptSubjectPinIntr from Pin class to HAL interrupt class. And moved the instance to button_class.h Changed files: - pin_class.h/cpp - hal_interrupts.h/cpp - button_class.h
    Moved some state_class methods from header to new cpp file.
    Changed added/files:
    - state_class.h/cpp
    - Makefile
    Updated event_listing.h for new events as per new development.
    Updated MCU sleep methods and updated/added them to main.cpp:
    Changed files:
    - mcu_sleep_class.h/cpp
    - main.cpp
    Updated RGB controller state machine for missing Node feedback events:
    Changed file: rgb_controller_state_machine.h
    [hal_interrupts.cpp, main.cpp, pin_class.cpp]
2015-04-20 Updated mcu_sleep_class.cpp to disable setting pins when sleep is enabled.
    Lower the number of PWM observers from six to three. Only three
    are used at one time.
2015-04-20 Updated state machine to enable/disable Awake Status LED via the controller state machine. Send enable/disable status led commands to node. Changed files: event_listing.h rgb_controller_state_machine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
    Updated main.cpp to fix comments and add sleeping the programming
    header pins.
    Fixed a comment in mcu_sleep_class.cpp.
    [main.cpp, rgb_controller_state_machine.h]

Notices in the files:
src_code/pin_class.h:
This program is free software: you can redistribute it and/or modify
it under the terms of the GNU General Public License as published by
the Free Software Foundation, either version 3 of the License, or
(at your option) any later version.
